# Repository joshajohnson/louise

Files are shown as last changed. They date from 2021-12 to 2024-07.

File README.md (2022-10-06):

# Louise

A project between Josh and RiotPunch to build a 75% alice keyboard with a southpaw numpad.

All the PCB files, case dxfs, and QMK firmware required to build your own are located in this repo.

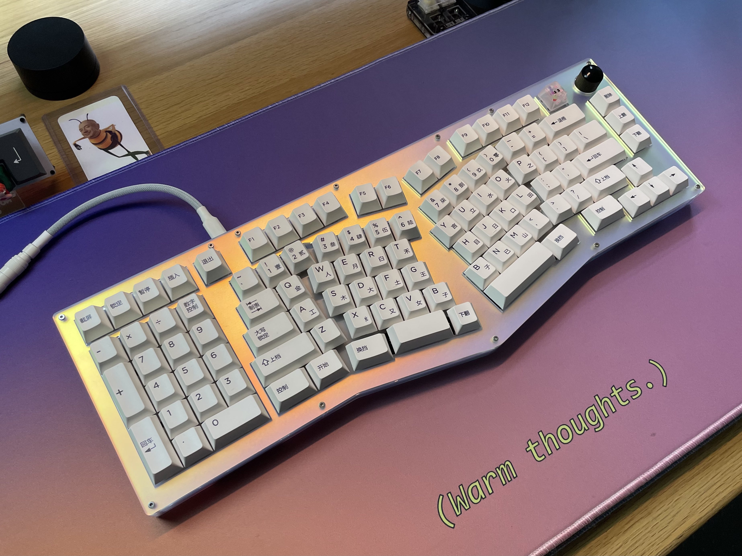
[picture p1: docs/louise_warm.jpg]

Thanks to [Warmthoughts](https://www.twitch.tv/warmthoughts) for the photo.

## BOM

| Type | Spec | Quantity | Notes |
|---|---|---|---|
| Standoff | M2 x 5mm | 2 | Wrist Wrest |
| Standoff | M2 x 8mm | 5 | Foot |
| Standoff | M2 x 10mm | 3 | Wrist Wrest |
| Standoff | M2 x 12mm | 12 | Case |
| Screw | M2 x 5mm | 4 | Wrist Wrest |
| Screw | M2 x 6mm | 40 | Everywhere |
| Encoder  | EC11, 15mm | 1 | PEC11R-4215F-S0024 |
| Knob | Max Dia 18mm | 1 | https://www.aliexpress.com/item/33000897896.html |

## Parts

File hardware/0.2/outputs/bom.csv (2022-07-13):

Item | Qty | Reference(s) | Value | LibPart | Footprint | LCSC | MPN | Manufacturer
1 | 1 | BZ1 | Buzzer | Device:Buzzer | josh-mechanical:Buzzer_Murata_PKMCS0909E |  | PKMCS0909E | Murata Electronics
2 | 27 | C1, C2, C3, C4, C5, C6, C8, C9, C10, C11, C13, C14, C16, C17, C18, C19, C20, C21, C22, C23, C30, C31, C32, C33, C34, C35, C36 | 100n | Device:C | Capacitor_SMD:C_0603_1608Metric | C14663 | CC0603KRX7R9BB104 | YAGEO
3 | 6 | C7, C12, C15, C24, C28, C29 | 4u7 | Device:C | Capacitor_SMD:C_0603_1608Metric | C19666 | CL10A475KO8NNNC | Samsung Electro-Mechanics
4 | 1 | C25 | 10u | Device:C | Capacitor_SMD:C_0603_1608Metric | C96446 | CL10A106MA8NRNC | Samsung Electro-Mechanics
5 | 2 | C26, C27 | 15p | Device:C | Capacitor_SMD:C_0603_1608Metric | C1644 | CL10C150JB8NNNC | Samsung Electro-Mechanics
6 | 111 | D1, D2, D3, D4, D5, D6, D11, D12, D13, D14, D15, D16, D21, D22, D23, D24, D25, D26, D29, D30, D31, D32, D33, D34, D38, D39, D40, D41, D42, D43, D47, D48, D49, D50, D54, D55, D56, D57, D58, D59, D61, D62, D63, D64, D65, D66, D67, D68, D69, D70, D71, D72, D74, D75, D76, D77, D78, D79, D80, D81, D82, D83, D84, D85, D86, D87, D88, D89, D90, D91, D92, D93, D94, D95, D96, D98, D99, D100, D101, D102, D103, D104, D105, D106, D107, D108, D109, D110, D111, D112, D113, D114, D115, D116, D117, D118, D119, D120, D121, D122, D123, D124, D125, D126, D127, D128, D129, D130, D131, D132, D133 | 1N4148 | Device:D_Small | Diode_SMD:D_SOD-123 | C81598 | 1N4148W | Semtech
7 | 18 | D7, D8, D9, D10, D17, D18, D19, D20, D27, D28, D35, D36, D37, D45, D51, D53, D134, D135 | WS2812B | LED:WS2812B | LED_SMD:LED_WS2812B_PLCC4_5.0x5.0mm_P3.2mm | C2761795 | WS2812B-B/W | Worldsemi
8 | 4 | D44, D46, D52, D60 | SK6812-MINI-E | josh-led:SK6812-MINI-E | josh-led:SK8612-MINI-E |  | SK6812-MINI-E | Shenzhen LED Color
9 | 1 | D73 | 1N4148 | Device:D | Diode_SMD:D_SOD-123 | C81598 | 1N4148W | Semtech
10 | 1 | D97 | BLUE | Device:LED | LED_SMD:LED_0603_1608Metric | C72041 | 19-217/BHC-ZL1M2RY/3T | Everlight Elec
11 | 1 | F1 | 500mA | Device:Polyfuse | josh-passives-smt:Fuse_0805_2012Metric | C66452 | SMD0805-050 | TECHFUSE
12 | 1 | J1 | USB_C_Receptacle_USB2.0 | Connector:USB_C_Receptacle_USB2.0 | josh-connectors:USB_C_Receptacle_HRO_TYPE-C-31-M-12 | C165948 | TYPE-C-31-M-12 | Korean Hroparts Elec
14 | 1 | Q1 | 2N7002 | Transistor_FET:BSS138 | Package_TO_SOT_SMD:SOT-23 | C8545 | 2N7002 | Changjiang Electronics Tech (CJ)
15 | 1 | Q2 | DTC123J | Transistor_BJT:DTC123J | Package_TO_SOT_SMD:SOT-23 | C145108 | DDTC123JCA-7-F | Diodes Incorporated
16 | 5 | R1, R2, R3, R4, R6 | 5K1 | Device:R | Resistor_SMD:R_0603_1608Metric | C23186 | 0603WAF5101T5E | UNI-ROYAL(Uniroyal Elec)
17 | 1 | R5 | 100K | Device:R | Resistor_SMD:R_0603_1608Metric | C25803 | 0603WAF1003T5E | UNI-ROYAL(Uniroyal Elec)
18 | 1 | R7 | 1K5 | Device:R | Resistor_SMD:R_0603_1608Metric | C22843 | 0603WAF1501T5E | UNI-ROYAL(Uniroyal Elec)
19 | 1 | R8 | 22R | Device:R | Resistor_SMD:R_0603_1608Metric | C23345 | 0603WAF220JT5E | UNI-ROYAL(Uniroyal Elec)
29 | 1 | SW57 | KMR2 | Switch:SW_Push | josh-buttons-switches:SW_Push_KMR2 | C99271 | KMR231GLFS | C&K
32 | 1 | U1 | SRV05-4 | Power_Protection:SRV05-4 | Package_TO_SOT_SMD:SOT-23-6 | C85364 | XC6206P332MR | ProTek Devices
33 | 1 | U2 | XC6206P332MR | Regulator_Linear:XC6206PxxxMR | Package_TO_SOT_SMD:SOT-23 | C5446 | XC6206P332MR | Torex Semicon
34 | 1 | U3 | STM32F303RBT6 | MCU_ST_STM32F3:STM32F303RCTx | Package_QFP:LQFP-64_10x10mm_P0.5mm | C130453 | STM32F303RBT6 | STMicroelectronics
35 | 1 | Y1 | 8MHz | Device:Crystal_GND24 | josh-oscillators:Crystal_SMD_3225-4Pin_3.2x2.5mm | C403948 | TAXM8M4RFDCET2T | TAE(Zhejiang Abel Elec)

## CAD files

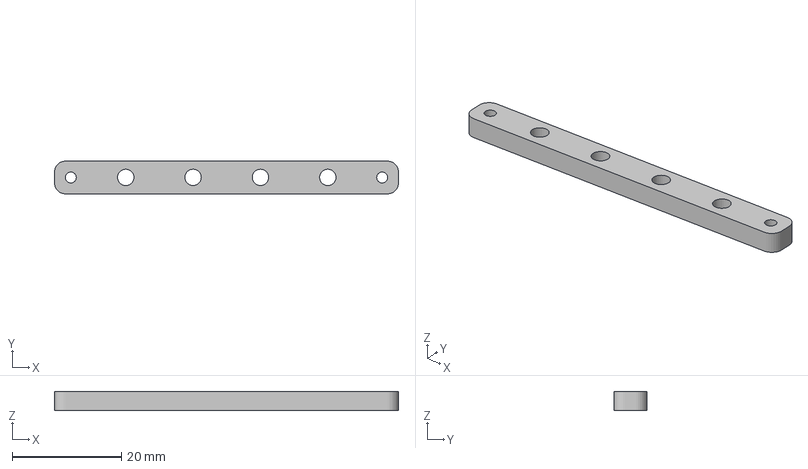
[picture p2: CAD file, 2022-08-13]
mechanical/louise-light-pipe.3mf
63.0 x 6.00 x 3.50 mm

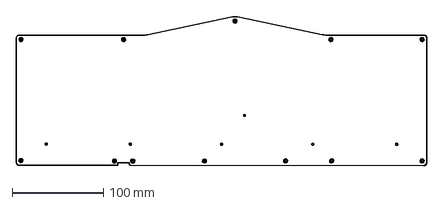
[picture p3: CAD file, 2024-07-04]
mechanical/louise-production-dxf/7-fixed.dxf
449.7 x 163.5 mm

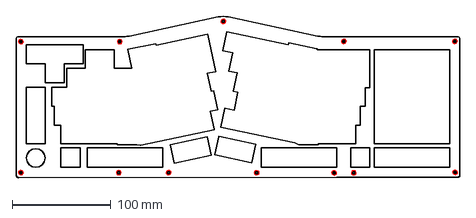
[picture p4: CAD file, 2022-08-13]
mechanical/louise-production-dxf/1.dxf
449.7 x 163.5 mm

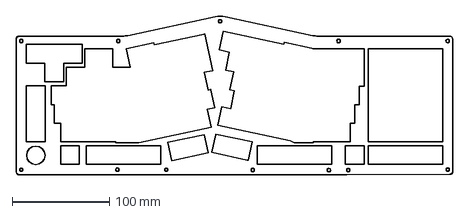
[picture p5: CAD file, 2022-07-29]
mechanical/louise-production-dxf/2.dxf
449.7 x 163.5 mm

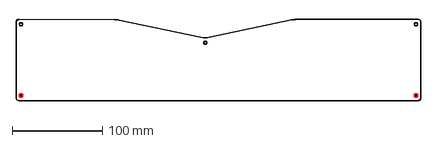
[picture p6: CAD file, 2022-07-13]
mechanical/louise-production-dxf/23.dxf
449.6 x 90.0 mm

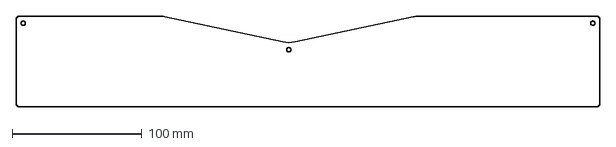
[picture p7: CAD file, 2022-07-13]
mechanical/louise-production-dxf/24.dxf
449.6 x 70.0 mm

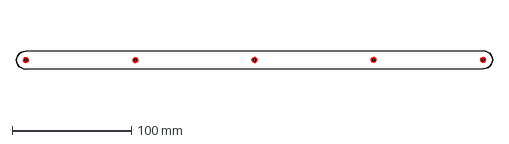
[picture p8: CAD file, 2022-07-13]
mechanical/louise-production-dxf/11.dxf
400.3 x 15.3 mm

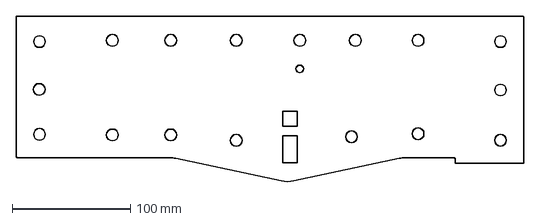
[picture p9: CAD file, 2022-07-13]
mechanical/louise-production-dxf/6-5-foam.dxf
429.6 x 140.0 mm

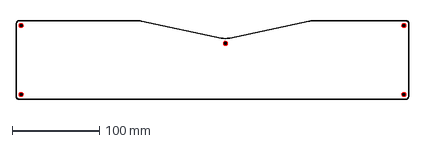
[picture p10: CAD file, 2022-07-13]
mechanical/louise-production-dxf/20.dxf
449.6 x 90.0 mm

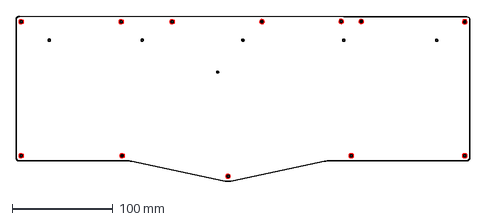
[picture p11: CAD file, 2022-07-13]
mechanical/louise-production-dxf/7.dxf
449.7 x 163.5 mm

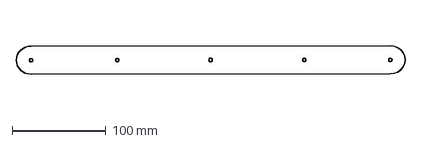
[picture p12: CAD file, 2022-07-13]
mechanical/louise-production-dxf/8.dxf
416.0 x 30.3 mm

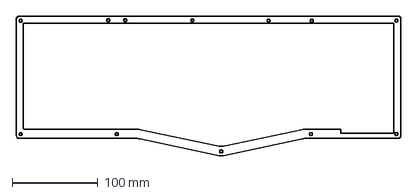
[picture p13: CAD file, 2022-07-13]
mechanical/louise-production-dxf/4.dxf
449.7 x 163.5 mm

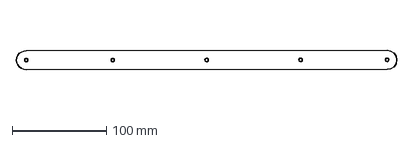
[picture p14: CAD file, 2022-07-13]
mechanical/louise-production-dxf/10.dxf
405.3 x 20.3 mm

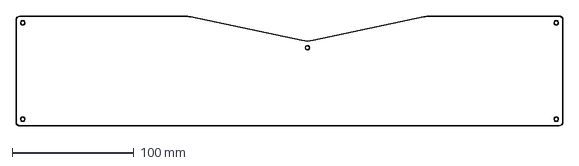
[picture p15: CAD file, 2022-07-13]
mechanical/louise-production-dxf/21and22.dxf
449.6 x 90.0 mm

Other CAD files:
mechanical/louise-production-dxf/5and6.dxf
mechanical/louise-production-dxf/25.dxf
mechanical/louise-production-dxf/3-pom.dxf
mechanical/louise-production-dxf/9.dxf
mechanical/louise-production-dxf/3-5-foam.dxf

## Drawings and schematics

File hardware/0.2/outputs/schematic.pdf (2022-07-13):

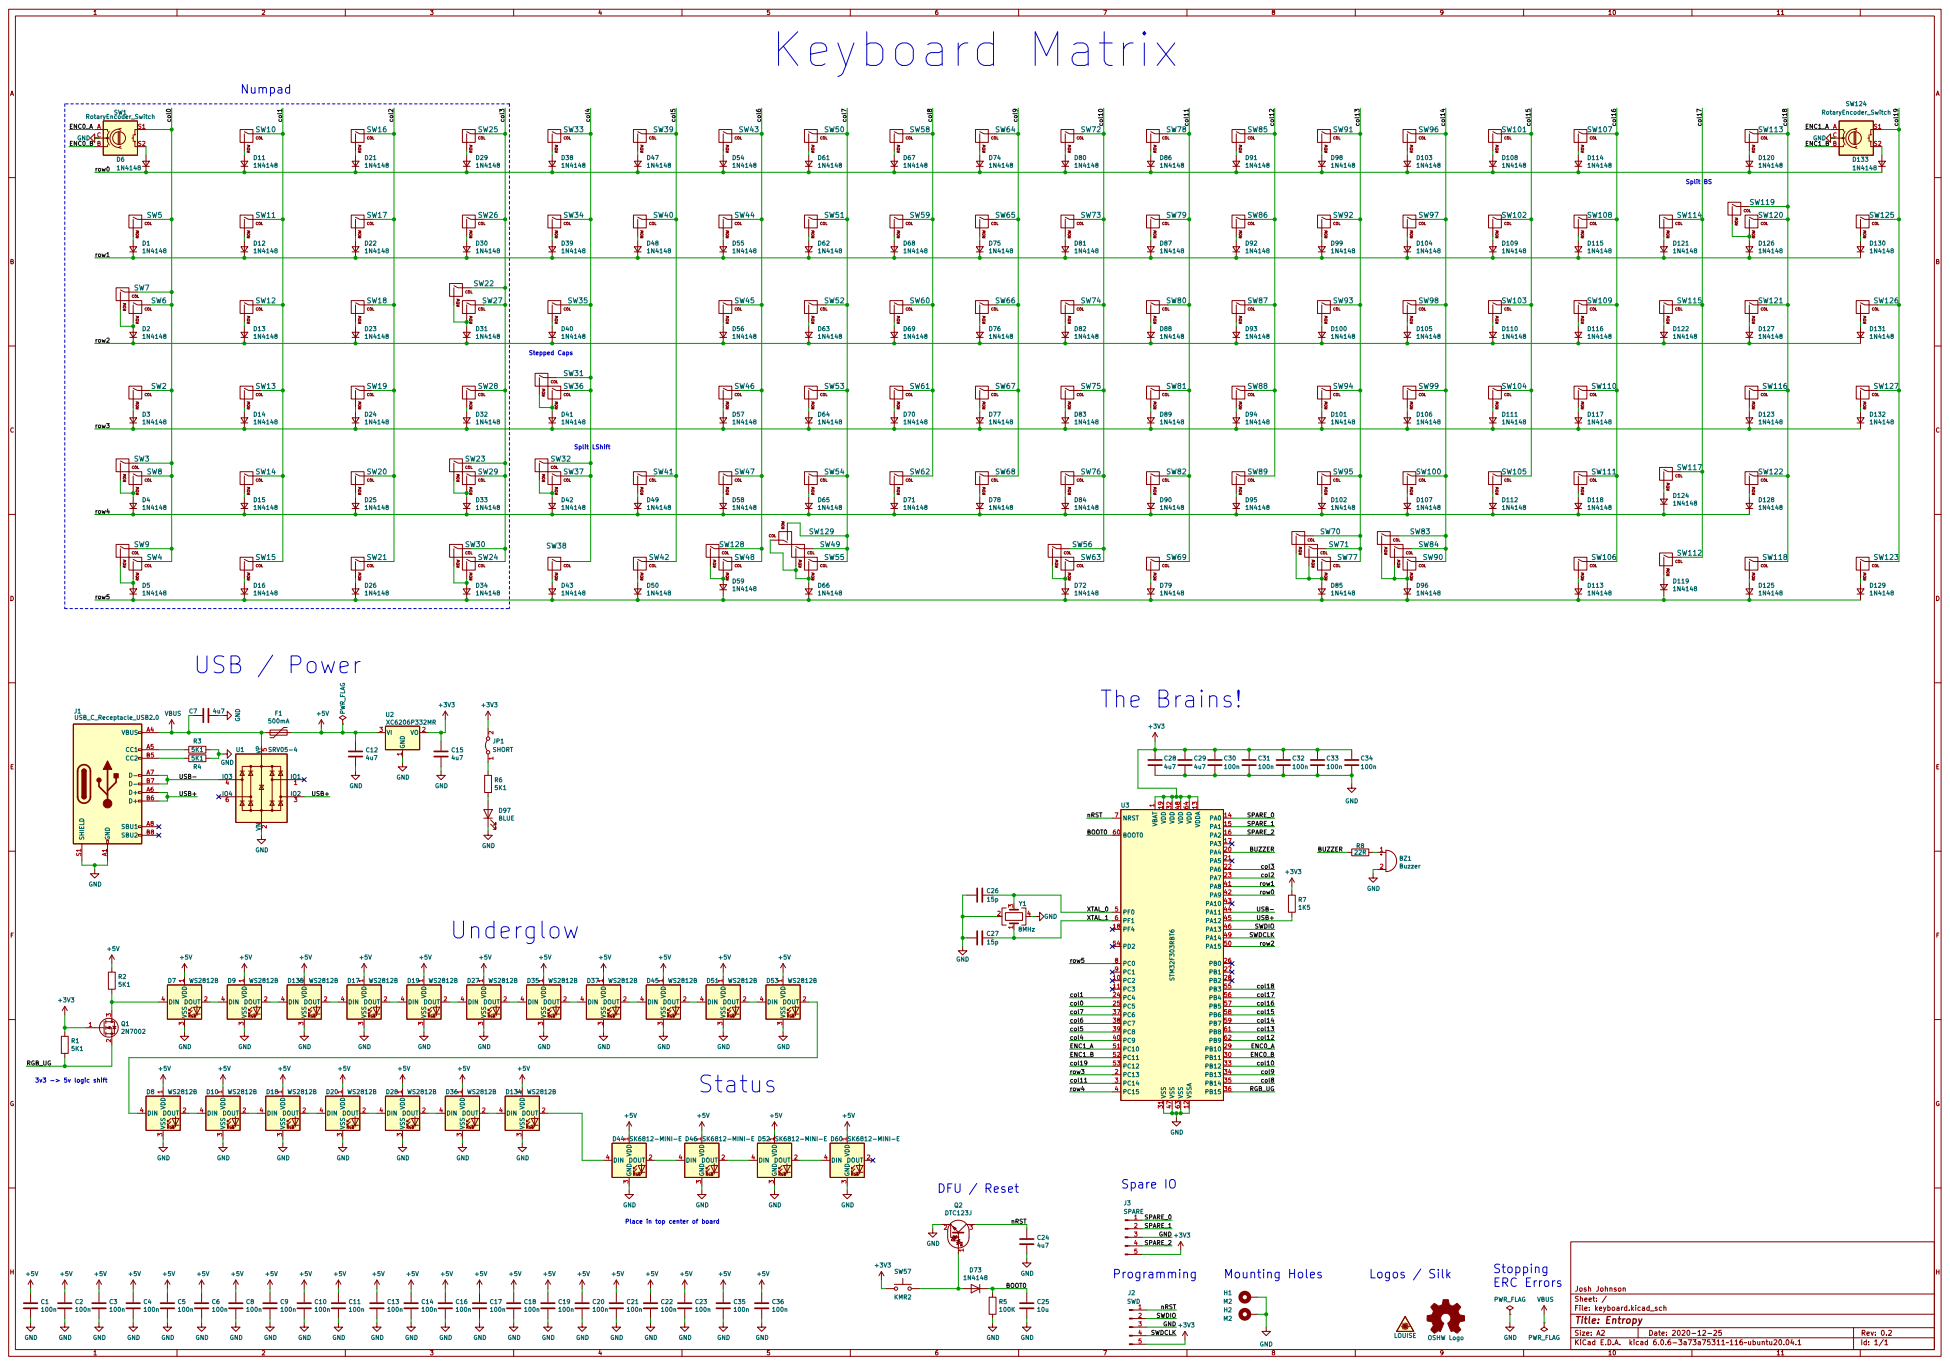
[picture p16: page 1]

Place in top center of board

ERC Errors Logos / Silk

File: keyboard.kicad_sch Sheet: / Josh Johnson

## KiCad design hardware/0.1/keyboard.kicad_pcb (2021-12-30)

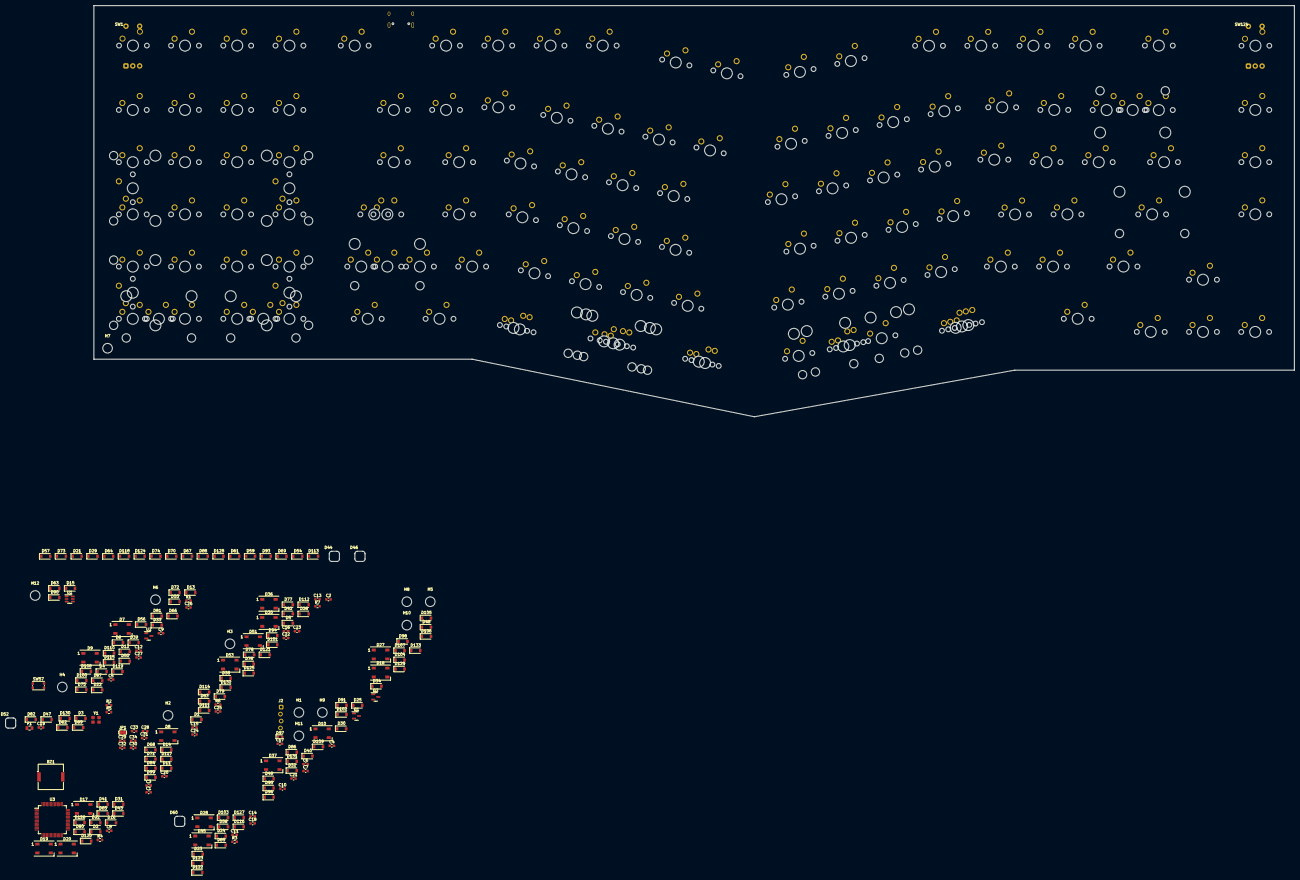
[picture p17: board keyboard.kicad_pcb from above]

Board: 2 copper layers, 470.2 x 299.5 mm, 327 parts (1 on the bottom side), 178 nets, no tracks yet.

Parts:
BZ1: Buzzer; Buzzer_Murata_PKMCS0909E
C1, C2, C3, C4, C5, C6, C8, C9, C10, C11, C13, C14, C16, C17, C18, C19, C20, C21, C22, C23, C30, C31, C32, C33, C34: 100n; C_0603_1608Metric
C7, C12, C15, C24, C28, C29: 4u7; C_0603_1608Metric
C25: 10u; C_0603_1608Metric
C26, C27: 15p; C_0603_1608Metric
D1, D2, D3, D4, D5, D6, D11, D12, D13, D14, D15, D16, D21, D22, D23, D24, D25, D26, D29, D30, D31, D32, D33, D34, D38, D39, D40, D41, D42, D43, D47, D48, D49, D50, D54, D55, D56, D57, D58, D59, D61, D62, D63, D64, D65, D66, D67, D68, D69, D70, D71, D72, D73, D74, D75, D76, D77, D78, D79, D80, D81, D82, D83, D84, D85, D86, D87, D88, D89, D90, D91, D92, D93, D94, D95, D96, D98, D99, D100, D101, D102, D103, D104, D105, D106, D107, D108, D109, D110, D111, D112, D113, D114, D115, D116, D117, D118, D119, D120, D121, D122, D123, D124, D125, D126, D127, D128, D129, D130, D131, D132, D133: 1N4148; D_SOD-123
D7, D8, D9, D10, D17, D18, D19, D20, D27, D28, D35, D36, D37, D45, D51, D53: WS2812B; LED_WS2812B_PLCC4_5.0x5.0mm_P3.2mm
D44, D46, D52, D60: SK6812-MINI-E; SK8612-MINI-E
D97: LED_RED; LED_0603_1608Metric
F1: 500mA; Fuse_0805_2012Metric
H1, H2, H3, H4, H5, H6, H7, H8, H9, H10, H11, H12: 3.5mm ID; MountingHole_3.5mm
J1: USB_C_Receptacle_USB2.0; USB_C_Receptacle_HRO_TYPE-C-31-M-12
J2: SWD; 4_PIN_THT_Staggered
JP1: SHORT; SolderJumper-2_P1.3mm_Bridged_RoundedPad1.0x1.5mm
LOGO3: OSHW Logo; OSHW_Logo_3.6x3.6_F.Mask
Q1: BSS138; SOT-23
Q2: DTC123J; SOT-23
R1, R2, R3, R4, R6: 5K1; R_0603_1608Metric
R5: 100K; R_0603_1608Metric
R7: 1K5; R_0603_1608Metric
SW1, SW124: RotaryEncoder_Switch; MX_KEYSWITCH_ENCODER
SW2, SW4, SW5, SW6, SW8, SW10, SW11, SW12, SW13, SW14, SW15, SW16, SW17, SW18, SW19, SW20, SW21, SW24, SW25, SW26, SW27, SW28, SW29, SW33, SW34, SW39, SW40, SW41, SW43, SW44, SW45, SW46, SW47, SW50, SW51, SW52, SW53, SW54, SW56, SW58, SW59, SW60, SW61, SW62, SW64, SW65, SW66, SW67, SW68, SW69, SW72, SW73, SW74, SW75, SW76, SW78, SW79, SW80, SW81, SW82, SW83, SW85, SW86, SW87, SW88, SW89, SW91, SW92, SW93, SW94, SW95, SW96, SW97, SW98, SW99, SW100, SW101, SW102, SW103, SW104, SW105, SW107, SW108, SW109, SW110, SW112, SW113, SW114, SW115, SW118, SW119, SW122, SW123, SW125, SW126, SW127: KEYSW; MXOnly-1U-NoLED
SW3, SW7, SW120: KEYSW; MXOnly-2U-NoLED
SW9, SW22, SW23, SW30, SW55: KEYSW; MXOnly-2U-ReversedStabilizers-NoLED
SW31, SW37, SW42, SW63, SW84, SW128: KEYSW; MXOnly-1.25U-NoLED
SW32, SW49, SW71, SW116, SW129: KEYSW; MXOnly-2.25U-ReversedStabilizers-NoLED
SW35, SW38, SW48, SW90, SW106, SW121: KEYSW; MXOnly-1.5U-NoLED
SW36, SW111, SW117: KEYSW; MXOnly-1.75U-NoLED
SW57: KMR2; SW_Push_KMR2
SW70: KEYSW; MXOnly-3U-ReversedStabilizers-NoLED
SW77: KEYSW; MXOnly-2.75U-ReversedStabilizers-NoLED
U1: SRV05-4; SOT-23-6
U2: XC6206P332MR; SOT-23
U3: STM32F303RCTx; LQFP-64_10x10mm_P0.5mm
Y1: 8MHz; Crystal_SMD_3225-4Pin_3.2x2.5mm

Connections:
+3V3: C15.2, C28.1, C29.1, C30.1, C31.1, C32.1, C33.1, C34.1, JP1.2 (B), Q1.1 (G), R1.1, R7.1, SW57.1, U2.2 (VO), U3.1 (VBAT), U3.13 (VDDA), U3.19 (VDD), U3.32 (VDD), U3.48 (VDD), U3.64 (VDD)
+5V: C1.2, C2.2, C3.2, C4.2, C5.2, C6.2, C8.2, C9.2, C10.2, C11.2, C12.2, C13.2, C14.2, C16.2, C17.2, C18.2, C19.2, C20.2, C21.2, C22.2, C23.2, D7.1 (VDD), D8.1 (VDD), D9.1 (VDD), D10.1 (VDD), D17.1 (VDD), D18.1 (VDD), D19.1 (VDD), D20.1 (VDD), D27.1 (VDD), D28.1 (VDD), D35.1 (VDD), D36.1 (VDD), D37.1 (VDD), D44.1 (VDD), D45.1 (VDD), D46.1 (VDD), D51.1 (VDD), D52.1 (VDD), D53.1 (VDD), D60.1 (VDD), F1.1, R2.1, U2.3 (VI)
/BOOT0: C25.1, D73.1 (K), R5.1, U3.60 (BOOT0)
/ENC0_A: SW1.A, U3.34 (PB13)
/ENC0_B: SW1.B, U3.35 (PB14)
/ENC1_A: SW124.A, U3.38 (PC7)
/ENC1_B: SW124.B, U3.39 (PC8)
/SWDCLK: J2.4, U3.49 (PA14)
/SWDIO: J2.2, U3.46 (PA13)
/USB+: J1.A6 (D+), J1.B6 (D+), U1.3 (IO2)
/USB-: J1.A7 (D-), J1.B7 (D-), U1.4 (IO3)
/USB_D+: R7.2, U3.45 (PA12)
/XTAL_0: C26.1, U3.5 (PF0), Y1.3
/XTAL_1: C27.1, U3.6 (PF1), Y1.1
/col0: SW1.S1, SW2.1 (COL), SW3.1 (COL), SW4.1 (COL), SW5.1 (COL), SW6.1 (COL), SW7.1 (COL), SW8.1 (COL), SW9.1 (COL), U3.33 (PB12)
/col1: SW10.1 (COL), SW11.1 (COL), SW12.1 (COL), SW13.1 (COL), SW14.1 (COL), SW15.1 (COL), U3.30 (PB11)
/col2: SW16.1 (COL), SW17.1 (COL), SW18.1 (COL), SW19.1 (COL), SW20.1 (COL), SW21.1 (COL), U3.29 (PB10)
/col3: SW22.1 (COL), SW23.1 (COL), SW24.1 (COL), SW25.1 (COL), SW26.1 (COL), SW27.1 (COL), SW28.1 (COL), SW29.1 (COL), SW30.1 (COL), U3.28 (PB2)
/col4: SW31.1 (COL), SW32.1 (COL), SW33.1 (COL), SW34.1 (COL), SW35.1 (COL), SW36.1 (COL), SW37.1 (COL), SW38.1 (COL), U3.62 (PB9)
/col5: SW39.1 (COL), SW40.1 (COL), SW41.1 (COL), SW42.1 (COL), U3.61 (PB8)
/col7: SW49.1 (COL), SW50.1 (COL), SW51.1 (COL), SW52.1 (COL), SW53.1 (COL), SW54.1 (COL), SW55.1 (COL), SW129.2 (ROW), U3.10 (PC2)
/col8: SW56.1 (COL), SW58.1 (COL), SW59.1 (COL), SW60.1 (COL), SW61.1 (COL), SW62.1 (COL), SW63.1 (COL), U3.9 (PC1)
/col9: SW64.1 (COL), SW65.1 (COL), SW66.1 (COL), SW67.1 (COL), SW68.1 (COL), SW69.1 (COL), U3.8 (PC0)
/col10: SW70.1 (COL), SW71.1 (COL), SW72.1 (COL), SW73.1 (COL), SW74.1 (COL), SW75.1 (COL), SW76.1 (COL), SW77.1 (COL), U3.2 (PC13)
/col11: SW78.1 (COL), SW79.1 (COL), SW80.1 (COL), SW81.1 (COL), SW82.1 (COL), U3.3 (PC14)
/col12: SW83.1 (COL), SW84.1 (COL), SW85.1 (COL), SW86.1 (COL), SW87.1 (COL), SW88.1 (COL), SW89.1 (COL), SW90.1 (COL), U3.4 (PC15)
/col13: D4.1 (K), D15.1 (K), D25.1 (K), D33.1 (K), D42.1 (K), D49.1 (K), D58.1 (K), D65.1 (K), D71.1 (K), D78.1 (K), D84.1 (K), D90.1 (K), D95.1 (K), D102.1 (K), D107.1 (K), D112.1 (K), D118.1 (K), D124.1 (K), D128.1 (K), SW43.1 (COL), SW44.1 (COL), SW45.1 (COL), SW46.1 (COL), SW47.1 (COL), SW48.1 (COL), SW91.1 (COL), SW92.1 (COL), SW93.1 (COL), SW94.1 (COL), SW95.1 (COL), SW128.1 (COL), U3.11 (PC3), U3.17 (PA3), U3.26 (PB0)
/col14: SW96.1 (COL), SW97.1 (COL), SW98.1 (COL), SW99.1 (COL), SW100.1 (COL), U3.22 (PA6)
/col15: SW101.1 (COL), SW102.1 (COL), SW103.1 (COL), SW104.1 (COL), SW105.1 (COL), SW106.1 (COL), U3.23 (PA7)
/col16: SW107.1 (COL), SW108.1 (COL), SW109.1 (COL), SW110.1 (COL), SW111.1 (COL), SW112.1 (COL), U3.24 (PC4)
/col17: SW113.1 (COL), SW114.1 (COL), SW115.1 (COL), SW116.1 (COL), SW117.1 (COL), SW118.1 (COL), U3.55 (PB3)
/col18: SW119.1 (COL), SW120.1 (COL), SW121.1 (COL), SW122.1 (COL), SW123.1 (COL), U3.56 (PB4)
/col19: SW124.S1, SW125.1 (COL), SW126.1 (COL), SW127.1 (COL), U3.57 (PB5)
/nRST: C24.1, J2.1, Q2.3 (C), U3.7 (NRST)
/row0: D6.1 (K), D11.1 (K), D21.1 (K), D29.1 (K), D38.1 (K), D47.1 (K), D54.1 (K), D61.1 (K), D67.1 (K), D74.1 (K), D80.1 (K), D86.1 (K), D91.1 (K), D98.1 (K), D103.1 (K), D108.1 (K), D114.1 (K), D120.1 (K), D133.1 (K), U3.51 (PC10)
/row1: D1.1 (K), D12.1 (K), D22.1 (K), D30.1 (K), D39.1 (K), D48.1 (K), D55.1 (K), D62.1 (K), D68.1 (K), D75.1 (K), D81.1 (K), D87.1 (K), D92.1 (K), D99.1 (K), D104.1 (K), D109.1 (K), D115.1 (K), D121.1 (K), D126.1 (K), D130.1 (K), U3.52 (PC11)
/row2: D2.1 (K), D13.1 (K), D23.1 (K), D31.1 (K), D40.1 (K), D56.1 (K), D63.1 (K), D69.1 (K), D76.1 (K), D82.1 (K), D88.1 (K), D93.1 (K), D100.1 (K), D105.1 (K), D110.1 (K), D116.1 (K), D122.1 (K), D127.1 (K), D131.1 (K), U3.53 (PC12)
/row3: D3.1 (K), D14.1 (K), D24.1 (K), D32.1 (K), D41.1 (K), D57.1 (K), D64.1 (K), D70.1 (K), D77.1 (K), D83.1 (K), D89.1 (K), D94.1 (K), D101.1 (K), D106.1 (K), D111.1 (K), D117.1 (K), D123.1 (K), D132.1 (K), U3.27 (PB1)
/row5: D5.1 (K), D16.1 (K), D26.1 (K), D34.1 (K), D43.1 (K), D50.1 (K), D59.1 (K), D66.1 (K), D72.1 (K), D79.1 (K), D85.1 (K), D96.1 (K), D113.1 (K), D119.1 (K), D125.1 (K), D129.1 (K), U3.25 (PC5)
/underglow: Q1.2 (S), R1.2, U3.36 (PB15)
GND: BZ1.2 (+), C1.1, C2.1, C3.1, C4.1, C5.1, C6.1, C7.1, C8.1, C9.1, C10.1, C11.1, C12.1, C13.1, C14.1, C15.1, C16.1, C17.1, C18.1, C19.1, C20.1, C21.1, C22.1, C23.1, C24.2, C25.2, C26.2, C27.2, C28.2, C29.2, C30.2, C31.2, C32.2, C33.2, C34.2, D7.3 (VSS), D8.3 (VSS), D9.3 (VSS), D10.3 (VSS), D17.3 (VSS), D18.3 (VSS), D19.3 (VSS), D20.3 (VSS), D27.3 (VSS), D28.3 (VSS), D35.3 (VSS), D36.3 (VSS), D37.3 (VSS), D44.3 (GND), D45.3 (VSS), D46.3 (GND), D51.3 (VSS), D52.3 (GND), D53.3 (VSS), D60.3 (GND), D97.1 (K), J1.A1 (GND), J1.A12 (GND), J1.B1 (GND), J1.B12 (GND), J1.S1 (SHIELD), J2.3, Q2.2 (E), R3.1, R4.2, R5.2, SW1.C, SW124.C, U1.2 (VN), U2.1 (GND), U3.12 (VSSA), U3.31 (VSS), U3.47 (VSS), U3.63 (VSS), Y1.2, Y1.4
unnamed: D1.2 (A), SW5.2 (ROW)
unnamed: D2.2 (A), SW6.2 (ROW), SW7.2 (ROW)
unnamed: D3.2 (A), SW2.2 (ROW)
unnamed: D4.2 (A), SW3.2 (ROW), SW8.2 (ROW)
unnamed: D5.2 (A), SW4.2 (ROW), SW9.2 (ROW)
unnamed: D6.2 (A), SW1.S2
unnamed: D7.2 (DOUT), D9.4 (DIN)
unnamed: D7.4 (DIN), Q1.3 (D), R2.2
unnamed: D10.2 (DOUT), D18.4 (DIN)
unnamed: D8.2 (DOUT), D10.4 (DIN)
unnamed: D11.2 (A), SW10.2 (ROW)
unnamed: D12.2 (A), SW11.2 (ROW)
unnamed: D13.2 (A), SW12.2 (ROW)
unnamed: D14.2 (A), SW13.2 (ROW)
unnamed: D15.2 (A), SW14.2 (ROW)
unnamed: D16.2 (A), SW15.2 (ROW)
unnamed: D17.2 (DOUT), D19.4 (DIN)
unnamed: D9.2 (DOUT), D17.4 (DIN)
unnamed: D18.2 (DOUT), D20.4 (DIN)
unnamed: D19.2 (DOUT), D27.4 (DIN)
unnamed: D20.2 (DOUT), D28.4 (DIN)
unnamed: D21.2 (A), SW16.2 (ROW)
unnamed: D22.2 (A), SW17.2 (ROW)
unnamed: D23.2 (A), SW18.2 (ROW)
unnamed: D24.2 (A), SW19.2 (ROW)
unnamed: D25.2 (A), SW20.2 (ROW)
unnamed: D26.2 (A), SW21.2 (ROW)
unnamed: D27.2 (DOUT), D35.4 (DIN)
unnamed: D28.2 (DOUT), D36.4 (DIN)
unnamed: D29.2 (A), SW25.2 (ROW)
unnamed: D30.2 (A), SW26.2 (ROW)
unnamed: D31.2 (A), SW22.2 (ROW), SW27.2 (ROW)
unnamed: D32.2 (A), SW28.2 (ROW)
unnamed: D33.2 (A), SW23.2 (ROW), SW29.2 (ROW)
unnamed: D34.2 (A), SW24.2 (ROW), SW30.2 (ROW)
unnamed: D35.2 (DOUT), D37.4 (DIN)
unnamed: D36.2 (DOUT), D44.4 (DIN)
unnamed: D37.2 (DOUT), D45.4 (DIN)
unnamed: D38.2 (A), SW33.2 (ROW)
unnamed: D39.2 (A), SW34.2 (ROW)
unnamed: D40.2 (A), SW35.2 (ROW)
unnamed: D41.2 (A), SW31.2 (ROW), SW36.2 (ROW)
unnamed: D42.2 (A), SW32.2 (ROW), SW37.2 (ROW)
unnamed: D43.2 (A), SW38.2 (ROW)
unnamed: D44.2 (DOUT), D46.4 (DIN)
unnamed: D45.2 (DOUT), D51.4 (DIN)
unnamed: D46.2 (DOUT), D52.4 (DIN)
unnamed: D47.2 (A), SW39.2 (ROW)
unnamed: D48.2 (A), SW40.2 (ROW)
unnamed: D49.2 (A), SW41.2 (ROW)
unnamed: D50.2 (A), SW42.2 (ROW)
unnamed: D51.2 (DOUT), D53.4 (DIN)
unnamed: D52.2 (DOUT), D60.4 (DIN)
unnamed: D8.4 (DIN), D53.2 (DOUT)
unnamed: D54.2 (A), SW43.2 (ROW)
unnamed: D55.2 (A), SW44.2 (ROW)
unnamed: D56.2 (A), SW45.2 (ROW)
unnamed: D57.2 (A), SW46.2 (ROW)
unnamed: D58.2 (A), SW47.2 (ROW)
unnamed: D59.2 (A), SW48.2 (ROW), SW128.2 (ROW)
unnamed: D61.2 (A), SW50.2 (ROW)
unnamed: D62.2 (A), SW51.2 (ROW)
unnamed: D63.2 (A), SW52.2 (ROW)
unnamed: D64.2 (A), SW53.2 (ROW)
unnamed: D65.2 (A), SW54.2 (ROW)
unnamed: D66.2 (A), SW49.2 (ROW), SW55.2 (ROW), SW129.1 (COL)
unnamed: D67.2 (A), SW58.2 (ROW)
unnamed: D68.2 (A), SW59.2 (ROW)
unnamed: D69.2 (A), SW60.2 (ROW)
unnamed: D70.2 (A), SW61.2 (ROW)
unnamed: D71.2 (A), SW62.2 (ROW)
unnamed: D72.2 (A), SW56.2 (ROW), SW63.2 (ROW)
unnamed: D73.2 (A), Q2.1 (B), SW57.2
unnamed: D74.2 (A), SW64.2 (ROW)
unnamed: D75.2 (A), SW65.2 (ROW)
unnamed: D76.2 (A), SW66.2 (ROW)
unnamed: D77.2 (A), SW67.2 (ROW)
unnamed: D78.2 (A), SW68.2 (ROW)
unnamed: D79.2 (A), SW69.2 (ROW)
unnamed: D80.2 (A), SW72.2 (ROW)
unnamed: D81.2 (A), SW73.2 (ROW)
unnamed: D82.2 (A), SW74.2 (ROW)
unnamed: D83.2 (A), SW75.2 (ROW)
unnamed: D84.2 (A), SW76.2 (ROW)
unnamed: D85.2 (A), SW70.2 (ROW), SW71.2 (ROW), SW77.2 (ROW)
unnamed: D86.2 (A), SW78.2 (ROW)
unnamed: D87.2 (A), SW79.2 (ROW)
unnamed: D88.2 (A), SW80.2 (ROW)
unnamed: D89.2 (A), SW81.2 (ROW)
unnamed: D90.2 (A), SW82.2 (ROW)
unnamed: D91.2 (A), SW85.2 (ROW)
unnamed: D92.2 (A), SW86.2 (ROW)
unnamed: D93.2 (A), SW87.2 (ROW)
unnamed: D94.2 (A), SW88.2 (ROW)
unnamed: D95.2 (A), SW89.2 (ROW)
unnamed: D96.2 (A), SW83.2 (ROW), SW84.2 (ROW), SW90.2 (ROW)
unnamed: D97.2 (A), R6.2
unnamed: D98.2 (A), SW91.2 (ROW)
unnamed: D99.2 (A), SW92.2 (ROW)
unnamed: D100.2 (A), SW93.2 (ROW)
unnamed: D101.2 (A), SW94.2 (ROW)
unnamed: D102.2 (A), SW95.2 (ROW)
unnamed: D103.2 (A), SW96.2 (ROW)
unnamed: D104.2 (A), SW97.2 (ROW)
unnamed: D105.2 (A), SW98.2 (ROW)
unnamed: D106.2 (A), SW99.2 (ROW)
unnamed: D107.2 (A), SW100.2 (ROW)
unnamed: D108.2 (A), SW101.2 (ROW)
unnamed: D109.2 (A), SW102.2 (ROW)
unnamed: D110.2 (A), SW103.2 (ROW)
unnamed: D111.2 (A), SW104.2 (ROW)
unnamed: D112.2 (A), SW105.2 (ROW)
unnamed: D113.2 (A), SW106.2 (ROW)
unnamed: D114.2 (A), SW107.2 (ROW)
unnamed: D115.2 (A), SW108.2 (ROW)
unnamed: D116.2 (A), SW109.2 (ROW)
unnamed: D117.2 (A), SW110.2 (ROW)
unnamed: D118.2 (A), SW111.2 (ROW)
unnamed: D119.2 (A), SW112.2 (ROW)
unnamed: D120.2 (A), SW113.2 (ROW)
unnamed: D121.2 (A), SW114.2 (ROW)
unnamed: D122.2 (A), SW115.2 (ROW)
unnamed: D123.2 (A), SW116.2 (ROW)
unnamed: D124.2 (A), SW117.2 (ROW)
unnamed: D125.2 (A), SW118.2 (ROW)
unnamed: D126.2 (A), SW119.2 (ROW), SW120.2 (ROW)
unnamed: D127.2 (A), SW121.2 (ROW)
unnamed: D128.2 (A), SW122.2 (ROW)
unnamed: D129.2 (A), SW123.2 (ROW)
unnamed: D130.2 (A), SW125.2 (ROW)
unnamed: D131.2 (A), SW126.2 (ROW)
unnamed: D132.2 (A), SW127.2 (ROW)
unnamed: D133.2 (A), SW124.S2
unnamed: J1.A5 (CC1), R3.2
unnamed: J1.B5 (CC2), R4.1
unnamed: JP1.1 (A), R6.1
VBUS: C7.2, F1.2, J1.A4 (VBUS), J1.A9 (VBUS), J1.B4 (VBUS), J1.B9 (VBUS), U1.5 (VP)

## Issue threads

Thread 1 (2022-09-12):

0.2 Errata

joshajohnson, 2022-09-12:
- Buzzer circuit non functional, for future revisions drive buzzer directly and use [this](https://lcsc.com/product-detail/Buzzers_Jiangsu-Huaneng-Elec-MLT-8530_C94599.html) part instead to get a louder output.

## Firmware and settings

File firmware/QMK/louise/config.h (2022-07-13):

/* Copyright 2022 joshajohnson, riotpunch

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
You should have received a copy of the GNU General Public License
along with this program.  If not, see <http://www.gnu.org/licenses/>.
*/

#pragma once

#include "config_common.h"

/* USB Device descriptor parameter */
#define VENDOR_ID       0x6A6A  // JJ
#define PRODUCT_ID      0xD134  // Louise
#define DEVICE_VER      0x0001
#define MANUFACTURER    Josh and Riot
#define PRODUCT         louise
#define DESCRIPTION     louise keyboard

/* key matrix */
#define MATRIX_ROWS 6
#define MATRIX_COLS 20

#define MATRIX_ROW_PINS { A9, A8, A15, C13, C15, C0 }
#define MATRIX_COL_PINS { C5, C4, A7, A6, C9, C8, C7, C6, B14, B13, B12, C14, B9, B8, B7, B6, B5, B4, B3, C12 }
#define UNUSED_PINS

#define DIODE_DIRECTION COL2ROW

/* Audio Things */
#define AUDIO_PIN A4

/* Rotary Encoder Things */
// #define ENCODER_DIRECTION_FLIP
#define ENCODERS_PAD_A { B10, C10 }
#define ENCODERS_PAD_B { B11, C11 }

/* Lighting things */
#define RGBLIGHT_LAYERS
#define RGBLIGHT_LAYERS_OVERRIDE_RGB_OFF

#define RGB_DI_PIN B15
#ifdef RGB_DI_PIN
/* 18 underglow, 4 status */
  #define RGBLED_NUM 22
  #define RGBLIGHT_HUE_STEP 8
  #define RGBLIGHT_SAT_STEP 8
  #define RGBLIGHT_VAL_STEP 8
  #define RGBLIGHT_LIMIT_VAL 255 /* The maximum brightness level */
  #define RGBLIGHT_SLEEP  /* If defined, the RGB lighting will be switched off when the host goes to sleep */
/*== all animations enable ==*/
  #define RGBLIGHT_ANIMATIONS
/*== or choose animations ==*/
//   #define RGBLIGHT_EFFECT_BREATHING
  #define RGBLIGHT_EFFECT_RAINBOW_MOOD
  #define RGBLIGHT_EFFECT_RAINBOW_SWIRL
//   #define RGBLIGHT_EFFECT_SNAKE
//   #define RGBLIGHT_EFFECT_KNIGHT
//   #define RGBLIGHT_EFFECT_CHRISTMAS
//   #define RGBLIGHT_EFFECT_STATIC_GRADIENT
//   #define RGBLIGHT_EFFECT_RGB_TEST
//   #define RGBLIGHT_EFFECT_ALTERNATING
/*== customize breathing effect ==*/
  /*==== (DEFAULT) use fixed table instead of exp() and sin() ====*/
  #define RGBLIGHT_BREATHE_TABLE_SIZE 256      // 256(default) or 128 or 64
  /*==== use exp() and sin() ====*/
  #define RGBLIGHT_EFFECT_BREATHE_CENTER 1.85  // 1 to 2.7
  #define RGBLIGHT_EFFECT_BREATHE_MAX    255   // 0 to 255
#endif

/* Debounce reduces chatter (unintended double-presses) - set 0 if debouncing is not needed */
#define DEBOUNCE 5

/* Tap delay for tap vs hold */
#define TAPPING_TERM 200

/* Slow down key press speed to ensure computer picks it up */
#define TAP_CODE_DELAY 20

/* Mouse Things */
#define MOUSEKEY_INTERVAL       20
#define MOUSEKEY_DELAY          300
#define MOUSEKEY_TIME_TO_MAX    100
#define MOUSEKEY_MAX_SPEED      3

/* Mechanical locking support. Use KC_LCAP, KC_LNUM or KC_LSCR instead in keymap */
#define LOCKING_SUPPORT_ENABLE
/* Locking resynchronize hack */
#define LOCKING_RESYNC_ENABLE

/* disable these deprecated features by default */
#ifndef LINK_TIME_OPTIMIZATION_ENABLE
  #define NO_ACTION_MACRO
  #define NO_ACTION_FUNCTION
#endif

// Status LED positions
#define LED0 18
#define LED1 19
#define LED2 20
#define LED3 21

// Up size of EEPROM to allow 4 layers with VIA
#define DYNAMIC_KEYMAP_EEPROM_MAX_ADDR 2047

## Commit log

2021-12-30 starting afresh
    [keyboard.kicad_pcb, keyboard.kicad_sch]
2021-12-31 WIP layout
    [keyboard.kicad_sch]
2021-12-31 schematic had unsaved changes
    [keyboard.kicad_sch]
2022-01-01 first pass layout
    [keyboard.kicad_sch]
2022-01-03 added more LEDs
    [keyboard.kicad_sch]
2022-01-04 clean up traces, silk TODO
    [keyboard.kicad_sch]
2022-01-05 add silk
    [keyboard.kicad_sch]
2022-01-07 0.1 off to fab
    [bom.csv, keyboard.kicad_sch]
2022-05-21 add laser cutter files and josh keymap
    [10.dxf, 11.dxf, 1and2.dxf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]
2022-07-13 bom fix
    [bom.csv, keyboard.kicad_sch]
2022-07-17 move usb connecor location for 0.2
    [bom.csv, keyboard.kicad_sch]
2022-07-29 update top layer dxf and make piezo louder
    [1.dxf, 1and2.dxf, 2.dxf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]
2022-08-13 update plate and bom
    [1.dxf, louise-light-pipe.3mf]
2022-10-06 update bom
2024-07-04 Layer 7 acrylic updated for recessed USB connector
    [7-fixed.dxf]

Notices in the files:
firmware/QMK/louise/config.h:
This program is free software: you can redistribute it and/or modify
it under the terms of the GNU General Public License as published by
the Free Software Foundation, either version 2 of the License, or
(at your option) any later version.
